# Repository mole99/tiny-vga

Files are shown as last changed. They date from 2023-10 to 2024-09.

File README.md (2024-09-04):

# Tiny VGA 

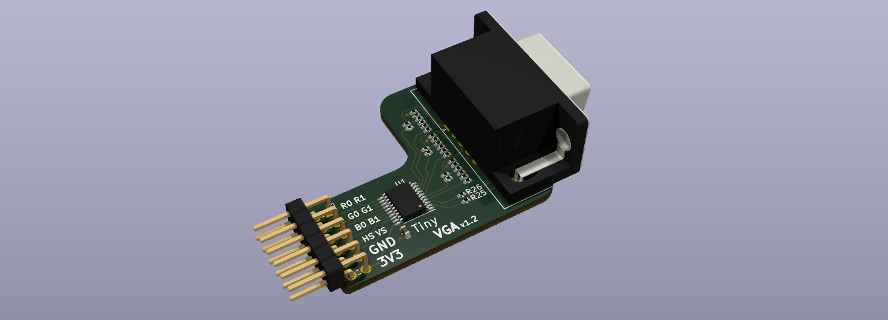
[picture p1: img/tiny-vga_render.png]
Tiny VGA 3D Render


Tiny VGA is a Pmod peripheral designed for [Tiny Tapeout](https://tinytapeout.com/), but can of course also be used with any other Pmod compatible hardware such as certain FPGA boards.

View the schematic online using [KiCanvas](https://kicanvas.org/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)!

**Why Yet Another Pmod VGA Peripheral?**

Tiny VGA only needs one Pmod connector to work. This means if you choose to use the output Pmod of the Tiny Tapeout PCB to connect to Tiny VGA, you still have the bidirectional and input Pmod available for other purposes.

It defines an interface for 2-bit per color VGA, so you can easily try other Tiny Tapeout designs that use the Tiny VGA pinout.

The board is designed in [KiCad](https://www.kicad.org/) and uses the [KiCAD JLCPCB tools](https://github.com/Bouni/kicad-jlcpcb-tools) to manage the assignment of components from the JLCPCB parts library.

## How Do I Get One? 

I do not sell Tiny VGAs, but you can order a few Tiny VGAs directly from PCB manufacturers for relatively little money. the cost per PCB gets cheaper if you order, say, ten at a time. You could give away the remaining Tiny VGAs to others who are located near you to help out the community :)

Search the Tiny Tapeout Discord server for others who could use one.

## Ordering Tiny VGA at JLCPCB

I have designed Tiny VGA so that it can be easily ordered fully-manufactured from JLCPCB. I am not sponsored or affiliated with JLCPCB in any way. If you would like to make it possible to produce Tiny VGA with other PCB manufacturers, you are welcome to contribute!

The [KiCAD JLCPCB tools](https://github.com/Bouni/kicad-jlcpcb-tools) needs to be installed to create the production files. Or you can use them right away under `pcb/jlcpcb/production_files/`.

1. Go to [JLCPCB](https://jlcpcb.com/) and create an account. 
2. Upload the gerber files from `pcb/jlcpcb/production_files/GERBER-tiny-vga.zip`.
3. You will get various options to choose from and a price offer. You don't really need to change anything, but you could change the quantity, choose a different color for the PCB and remove the order number.
3. Next, enable "PCB Assembly", keep the settings as they are and confirm. You will be forwarded to a new page with a view of the PCB. 
4. Click on "Next" and you will be prompted to upload the BOM and CPL file which you can find under `pcb/jlcpcb/production_files/BOM-tiny-vga.csv` and `pcb/jlcpcb/production_files/CPL-tiny-vga.csv`. 
5. The next page shows you all the parts that will be placed. 
6. Again, "Next" will lead you to the component placement page where you can confirm the placement of the parts. Here you might need to rotate some of the components.
7. Click on "Next" and you will get your quote for the assembled PCBs. Proceed to the checkout and you are done :D

## Tiny VGA Pinout

Pin numbering according to Pmod specification.

| Pin | Signal | Pin | Signal |
| :-: | :----: | :-: | :----: |
| top row | | bottom row | |
| 1 | R1 | 7 | R0 |
| 2 | G1 | 8 | G0 |
| 3 | B1 | 9 | B0 |
| 4 | VS | 10  | HS |
| 5 | GND | 11  | GND |
| 6 | VCC | 12  | VCC |

> [!NOTE]  
> R0, G0, B0 are the least significant bits\
> R1, G1, B1 are the most significant bits\
> VS is the vertical sync\
> HS is the horizontal sync\
> VCC must be 3V3

## Board Images

### v1.0

Tiny VGA v1.0 board manufactured by JLCPCB, including SMD components (THT connectors manually soldered).

| | |
|---|---|
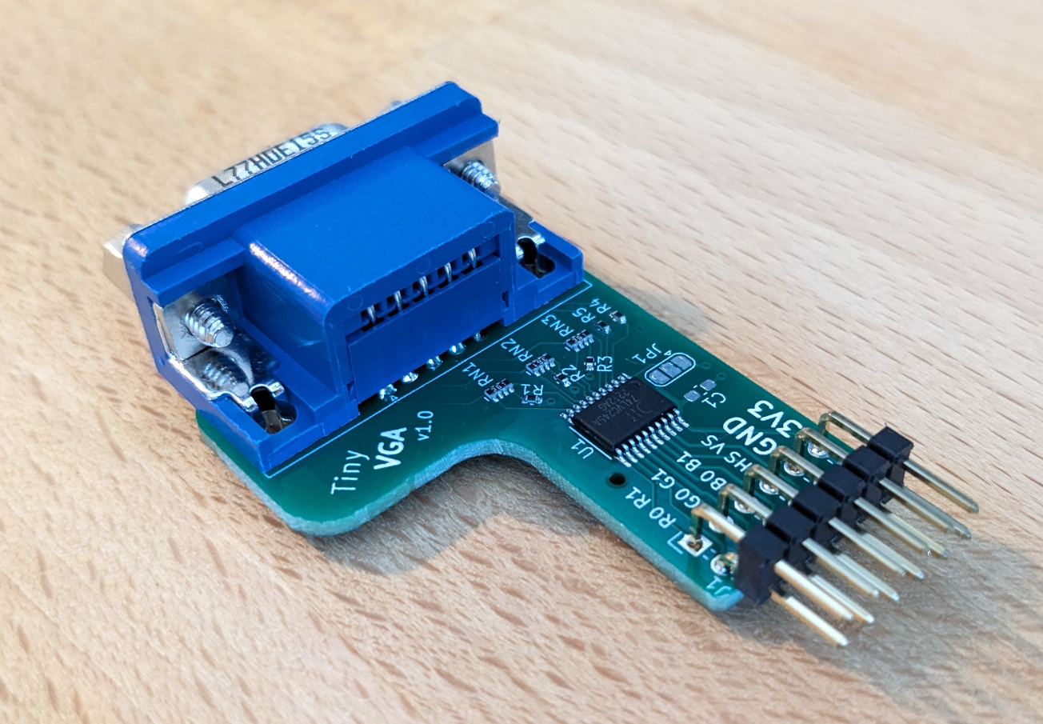
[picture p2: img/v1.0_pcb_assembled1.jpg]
Tiny VGA v1.0 left
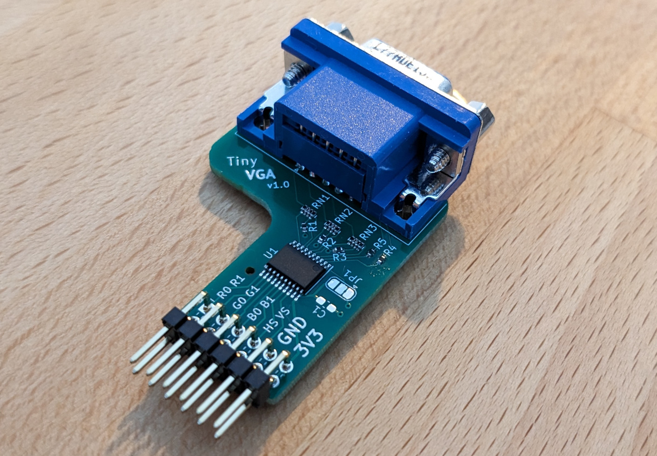
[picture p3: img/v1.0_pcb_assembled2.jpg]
Tiny VGA v1.0 right
|  |  |

### v1.2

Tiny VGA v1.2 board manufactured by JLCPCB, including SMD components and THT connectors.

| | |
|---|---|
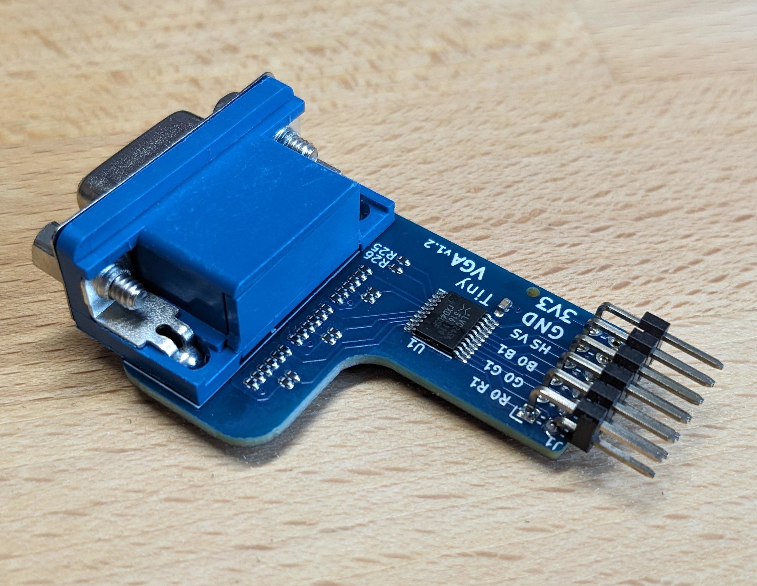
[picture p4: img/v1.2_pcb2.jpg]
Tiny VGA v1.2 left
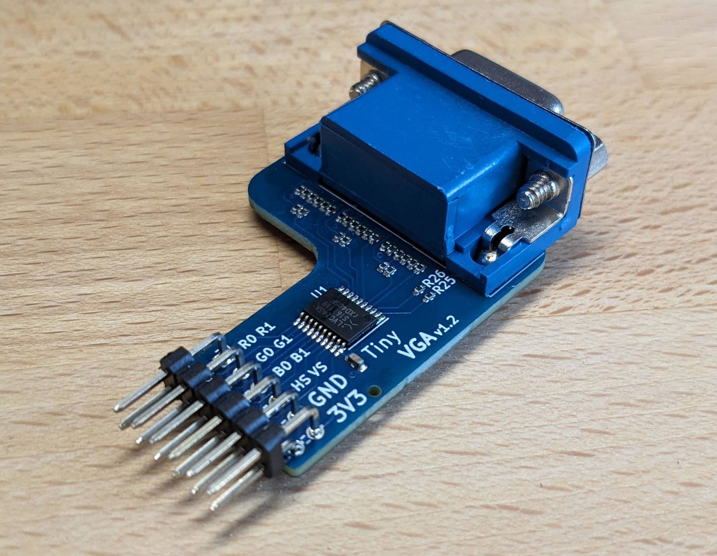
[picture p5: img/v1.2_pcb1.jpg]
Tiny VGA v1.2 right
|  |  |

## Demo

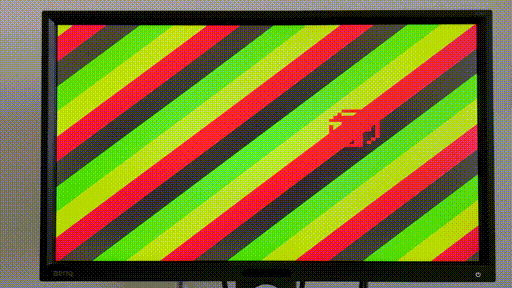
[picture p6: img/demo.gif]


The demo output is 800x600 SVGA and the quality is excellent in real life.

## License

This work is licensed under a
[Creative Commons Attribution-ShareAlike 4.0 International License][cc-by-sa].

[cc-by-sa]: http://creativecommons.org/licenses/by-sa/4.0/

Copyright (c) Leo Moser

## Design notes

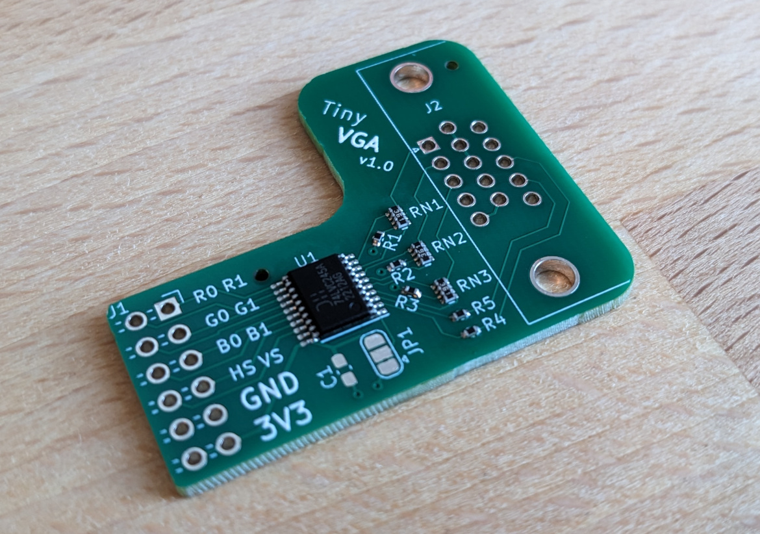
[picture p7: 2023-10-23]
img/v1.0_pcb_smd.jpg

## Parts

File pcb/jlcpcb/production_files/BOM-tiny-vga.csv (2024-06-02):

Comment | Designator | Footprint | LCSC
1k | R14,R22,R6 | R_0402_1005Metric | C11702
VGA | J2 | VGA-002 | C138387
100n | C1 | C_0603_1608Metric | C14663
220R | R12,R20,R4 | R_0402_1005Metric | C25091
470 | R1,R11,R16,R17,R19,R24,R3,R8,R9 | R_0402_1005Metric | C25117
49.9R | R25,R26 | R_0402_1005Metric | C25120
1.5k | R10,R13,R15,R18,R2,R21,R23,R5,R7 | R_0402_1005Metric | C25867
PMOD | J1 | PinHeader_2x06_P2.54mm_Horizontal | C2935938
74LVC245APW,118 | U1 | TSSOP-20_4.4x6.5mm_P0.65mm | C6082

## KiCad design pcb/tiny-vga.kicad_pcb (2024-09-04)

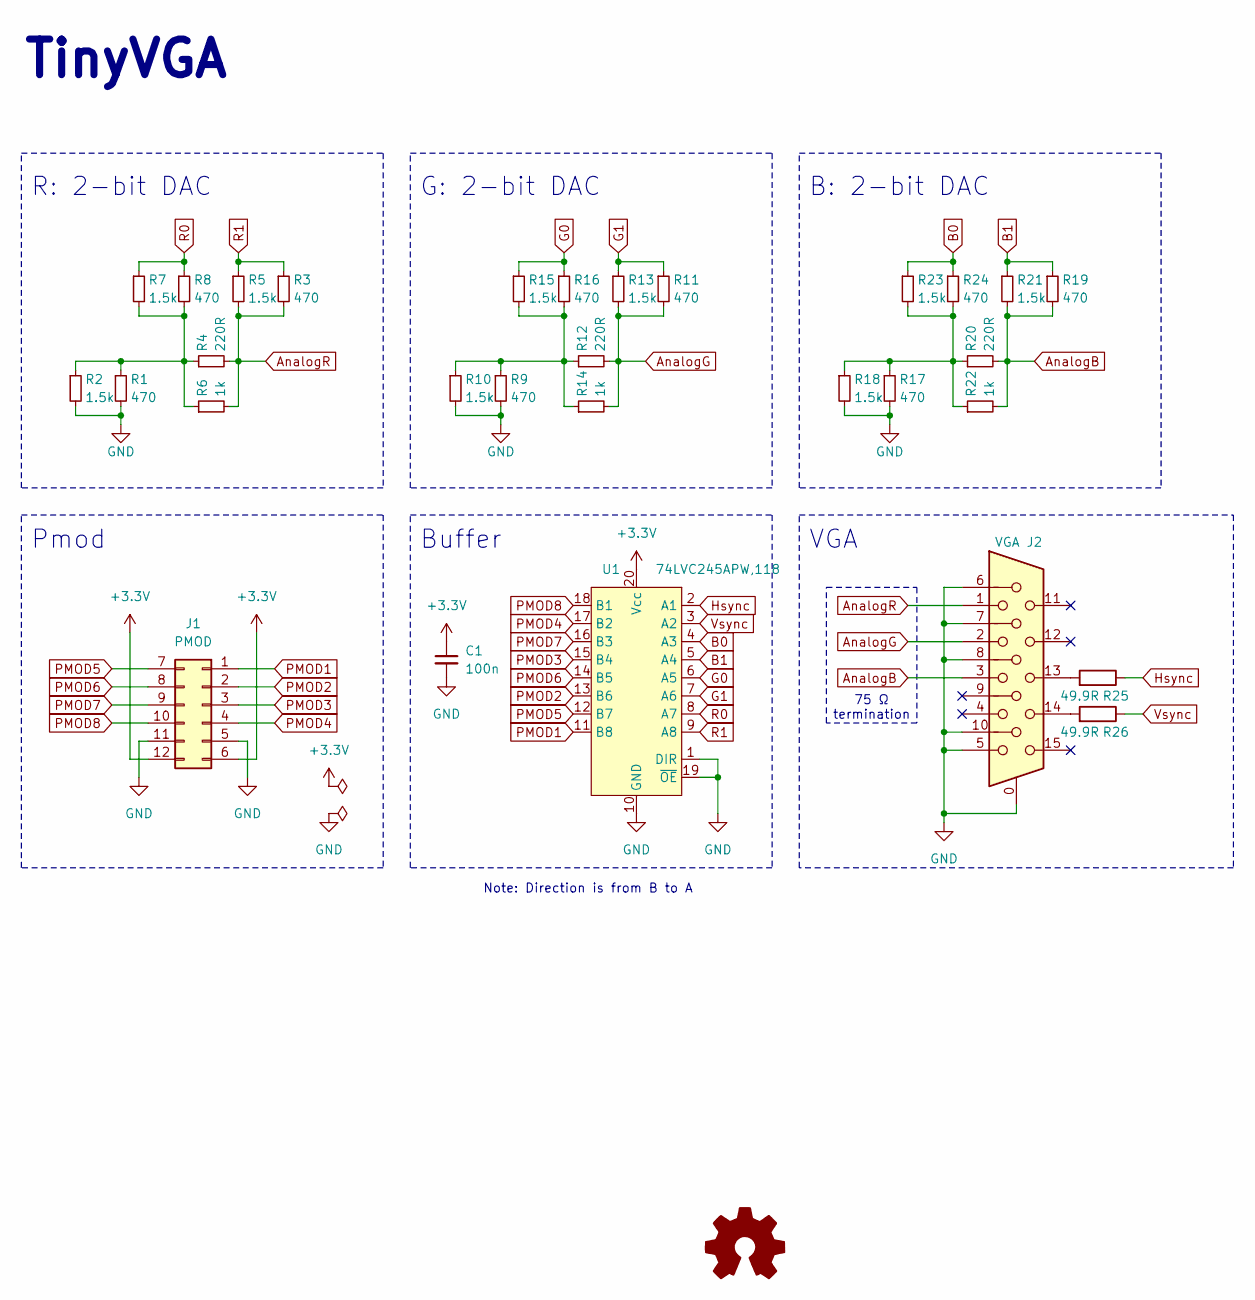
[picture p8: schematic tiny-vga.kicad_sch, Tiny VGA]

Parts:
C1: 100n; C_0603_1608Metric; MPN CGA3E3X7S2A104M080AB; LCSC C14663
J1: PMOD; PinHeader_2x06_P2.54mm_Horizontal; MPN 826634-6; LCSC C2935938
J2: VGA; DSUB-15-HD_Female_Horizontal_P2.29x1.98mm_EdgePinOffset8.35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; MPN L77HDE15SD1CH4FVGA; LCSC C138387
R1, R3, R8, R9, R11, R16, R17, R19, R24: 470; R_0402_1005Metric; MPN RCC0402470RFKED; LCSC C25117
R2, R5, R7, R10, R13, R15, R18, R21, R23: 1.5k; R_0402_1005Metric; MPN RCC04021K50FKED; LCSC C25867
R4, R12, R20: 220R; R_0402_1005Metric; MPN RCS0402220RFKED; LCSC C25091
R6, R14, R22: 1k; R_0402_1005Metric; MPN CRCW04021K00FKED; LCSC C11702
R25, R26: 49.9R; R_0402_1005Metric; MPN ERJ-2RKF49R9X; LCSC C25120
U1: 74LVC245APW,118; TSSOP-20_4.4x6.5mm_P0.65mm; MPN 74LVC245APW,118; LCSC C6082

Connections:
+3.3V: C1.1, J1.6, J1.12, U1.20 (Vcc)
AnalogB: J2.3, R19.2, R20.2, R21.2, R22.2
AnalogG: J2.2, R11.2, R12.2, R13.2, R14.2
AnalogR: J2.1, R3.2, R4.2, R5.2, R6.2
B0: R23.1, R24.1, U1.4 (A3)
B1: R19.1, R21.1, U1.5 (A4)
G0: R15.1, R16.1, U1.6 (A5)
G1: R11.1, R13.1, U1.7 (A6)
GND: C1.2, J1.5, J1.11, J2.0, J2.5, J2.6, J2.7, J2.8, J2.10, R1.2, R2.2, R9.2, R10.2, R17.2, R18.2, U1.1 (DIR), U1.10 (GND), U1.19 (~OE)
Hsync: R25.1, U1.2 (A1)
unnamed: J2.13, R25.2
unnamed: J2.14, R26.2
unnamed: R1.1, R2.1, R4.1, R6.1, R7.2, R8.2
unnamed: R9.1, R10.1, R12.1, R14.1, R15.2, R16.2
unnamed: R17.1, R18.1, R20.1, R22.1, R23.2, R24.2
PMOD1: J1.1, U1.11 (B8)
PMOD2: J1.2, U1.13 (B6)
PMOD3: J1.3, U1.15 (B4)
PMOD4: J1.4, U1.17 (B2)
PMOD5: J1.7, U1.12 (B7)
PMOD6: J1.8, U1.14 (B5)
PMOD7: J1.9, U1.16 (B3)
PMOD8: J1.10, U1.18 (B1)
R0: R7.1, R8.1, U1.8 (A7)
R1: R3.1, R5.1, U1.9 (A8)
Vsync: R26.1, U1.3 (A2)

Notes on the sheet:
G: 2-bit DAC
Pmod
75 Ω termination
R: 2-bit DAC
TinyVGA
VGA
B: 2-bit DAC
Note: Direction is from B to A
Buffer

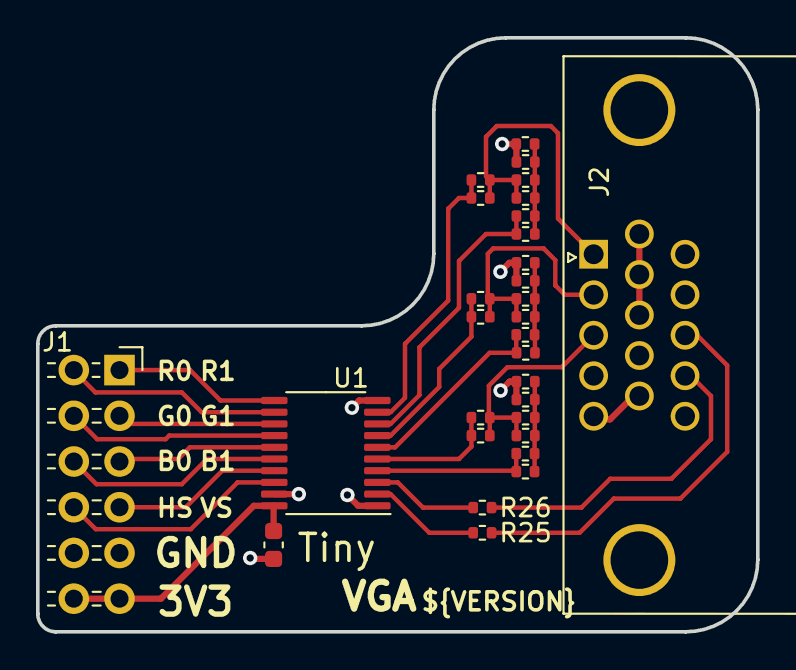
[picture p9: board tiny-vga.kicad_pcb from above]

Board: 2 copper layers, 40.0 x 33.0 mm, 30 parts (0 on the bottom side), 26 nets.

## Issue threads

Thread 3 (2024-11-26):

Are Vertical and horizontal sync active low or active high?

xzores, 2024-11-26:
Are Vertical and horizontal sync active low or active high?

mole99, 2024-11-26:
Hi @xzores, that depends on which signal timing you want to achive. For 640x480 @ 60Hz the polarity is negative for both signals. Please have a look at this website for a complete list: http://www.tinyvga.com/vga-timing

Tiny VGA simply uses a buffer and therefore does not invert the polarity of your signals.

Closed 2024-11-26.

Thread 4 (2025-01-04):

Dimension information for  JLCPCB order is missing from README

yuri-panchul, 2025-01-04:
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

Please add information what dimensions should we put for the JLCPCB order. It does not allow to add PCB Assembly without this information, even with Gerber file.

mole99, 2025-01-04:
Hi @yuri-panchul, it seems something went wrong with your upload. I tried it just now by uploading the [Gerbers](https://github.com/mole99/tiny-vga/blob/main/pcb/jlcpcb/production_files/GERBER-tiny-vga.zip) to JLCPCB and it works fine:

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

Are you using the zipped Gerbers?

yuri-panchul, 2025-01-04:
Yes, I was using zipped gerber

yuri-panchul, 2025-01-04:
It works now

Closed 2025-01-04.

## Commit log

2023-10-23 Tiny VGA v1.0
    [tiny-vga-CuBottom.gbr, tiny-vga-CuTop.gbr, tiny-vga-EdgeCuts.gbr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]
2023-10-23 Add BOM and CPL
    [BOM-tiny-vga.csv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]
2023-11-19 Update parts for aisler
    [tiny-vga.kicad_pcb, tiny-vga.kicad_sch]
2023-12-09 Add AISLER support
    [BOM-tiny-vga.csv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]
2024-02-03 Update trace widths
    [BOM-tiny-vga.csv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]
2024-06-02 Final v1.2, tested and working
    [BOM-tiny-vga.csv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]
2024-09-04 Update to KiCad 8.0
    [tiny-vga.kicad_pcb, tiny-vga.kicad_sch]
2024-09-04 Add board render and link to schematic

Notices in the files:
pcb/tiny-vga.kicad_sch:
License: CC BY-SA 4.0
